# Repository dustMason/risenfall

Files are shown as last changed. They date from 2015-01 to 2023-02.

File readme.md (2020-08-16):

LED specs
===

All values calculated based on a 5v supply.

Table 1
---

Number | Color | Wattage | Current Draw | Fwd Voltage    | Resistor
------ | ----- | ------- | ------------ | -------------- | -------------
1      | White | ?       | 18mA         | 3-3.2v         | 120ohm / 1/8W
2      | White | ?       | 18mA         | 3-3.2v         | 120ohm / 1/8W
3      | White | 1W      | 330mA        | 3.2v           | 5.6ohm / 1W
4      |       |         |              |                | (missing LED)
5      | White | 1W      | 330mA        | 3.2v           | 5.6ohm / 1W
6      | White | 1W      | 330mA        | 3.2v           | 5.6ohm / 1W
7      | White | ?       | 18mA         | 3.2v           | 120ohm / 1/8W
8      | White | 1W      | 330mA        | 3.2v           | 5.6ohm / 1W

Table 2
---

Number | Color | Wattage | Current Draw | Fwd Voltage    | Resistor
------ | ----- | ------- | ------------ | -------------- | -------------
9      | Green | ?       | 16mA         | 2.9-3.1v       | 120ohm / 1/4W
10     | Green | ?       | 16mA         | 2.9-3.1v       | 220ohm / 1/4W
11     | White | ?       | 20mA         | 3-3.2v         | 100ohm / 1/8W
12     | Blue  | ?       | 18mA         | 3-3.2v         | 120ohm / 1/8W
13     | White | ?       | ?            | ?              | ? (light is dead)
14     | Blue  | ?       | 18mA         | 3-3.2v         | 120ohm / 1/8W
15     | White | ?       | 20mA         | 3-3.2v         | 100ohm / 1/8W
16     | Blue  | ?       | 18mA         | 3-3.2v         | 120ohm / 1/8W 
17     | White | ?       | 20mA         | 3-3.2v         | 100ohm / 1/8W 
18     | Blue  | ?       | 18mA         | 3-3.2v         | 120ohm / 1/8W 
19     | White | 1W      | 330mA        | 3.2v           | 5.6ohm / 1W

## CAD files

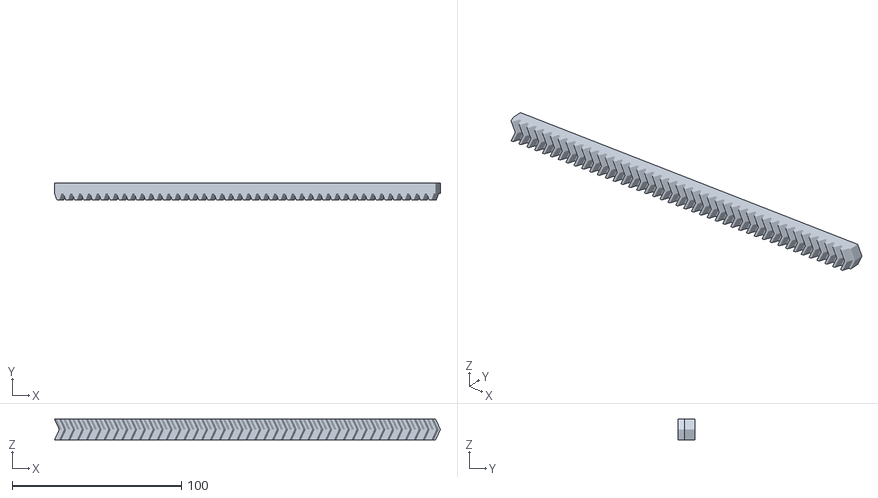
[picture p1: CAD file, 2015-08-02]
models/herringbone-rack.stl
228.0 x 9.85 x 12.2

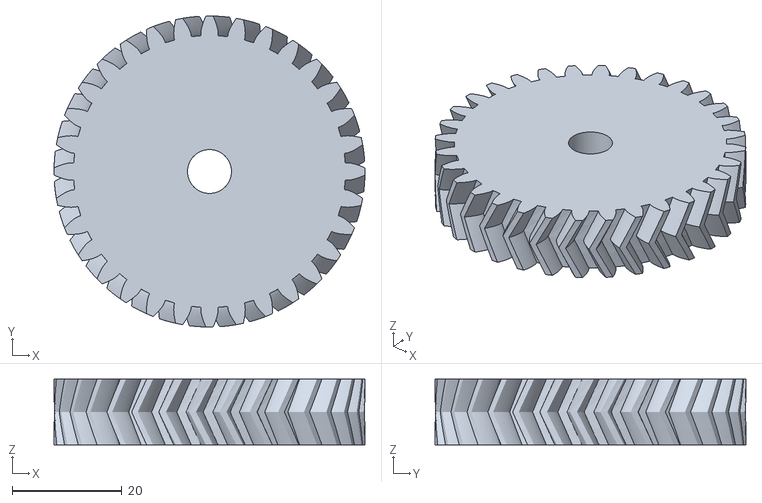
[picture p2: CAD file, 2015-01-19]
models/herringbone-gear.stl
56.7 x 56.7 x 12.0

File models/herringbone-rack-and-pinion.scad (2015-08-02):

// Parametric Modular Rack Andrew Ziobro
//Based on the work of MattMoses and Fdavies and Mark "Ckaos" Moissette:
//http://forums.reprap.org/read.php?1,51452,52099#msg-52099
//and Forrest Higgs:
// http://technocraticanarchist.blogspot.com/2010/01/high-speed-alternative-to-belts.html
//and http://www.thingiverse.com/thing:6011 info at :www.kaosat.net 
//and http://www.thingiverse.com/thing:3575 Parametic_involute_gear_v5.0
//It is licensed under the Creative Commons - GNU GPL license.
// © 2011 by Andrew Ziobro


//Download parametric_involute_gear_v5.0.scad from http://www.thingiverse.com/thing:3575
use <parametric_involute_gear_v5.0.scad>;

$fn=50;
pi=3.1415926535897932384626433832795;

innerRadius=5.1;
borders=1;
diametralPitch=12; // was 12
numberOfTeeth=43;
pressureAngle=20*pi/180;
centerAngle=25; // angle at center of teeth

rack(innerRadius,borders,diametralPitch,numberOfTeeth,pressureAngle,centerAngle);
// translate([0,-35.4,0]) {
// makeTetrixGear();
// }

module makeTetrixGear() {
	wheelSize=12;
	rotate([0,0,180]) {
		translate(0) {
			gear (
				number_of_teeth=32,
				circular_pitch=300,
				diametral_pitch=diametralPitch,
				pressure_angle=19.34,
				gear_thickness=wheelSize/2,
				rim_thickness=wheelSize/2,
				hub_thickness=0,
				bore_diameter=8,
				backlash=0,twist=centerAngle/4,involute_facets=15
			);
		}
		translate([0,0,wheelSize/2]) {
			rotate([0,0,-centerAngle/4]) {
				gear (
					number_of_teeth=32,
					circular_pitch=300,
					diametral_pitch=diametralPitch,
					pressure_angle=19.34,
					gear_thickness=wheelSize/2,
					rim_thickness=wheelSize/2,
					hub_thickness=0,
					bore_diameter=8,
					backlash=0,twist=-centerAngle/4,involute_facets=15
				);
			}
		}
	}
}


			
//rotate (a=[0,0,0]) translate([0,0,-1]) difference(){

module rack(innerRadius,borders,P,N,PA,CA) {
	// P = diametral pitch
	// N = number of teeth
	// PA = pressure angle in radians
	// x, y = linear offset distances
	a = 1/P; // addendum (also known as "module")
	d = 1.25/P; // dedendum (this is set by a standard)
	multiplier=20;//20
	height=(d+a)*multiplier;
	// echo(height);
	
	// find the tangent of pressure angle once
	tanPA = tan(PA*(180/pi));
	// length of bottom and top horizontal segments of tooth profile
	botL = (pi/P/2 - 2*d*tanPA)*multiplier;
	topL =( pi/P/2 - 2*a*tanPA)*multiplier;

	slantLng=tanPA*height;
	realBase=2*slantLng+topL;
	
	offset=topL+botL+2*slantLng;
	length=(realBase+botL)*N;
	echo("Offset:",offset);
	supportSize=(innerRadius+borders)*2;

	//calculate tooth params
	basesegmentL=realBase/2;
	basesegmentW=supportSize/2;

	topsegmentL=topL/2;
	topsegmentW=supportSize/2;

	baseoffsetY=tan(CA)*basesegmentW;
	topoffsetY=tan(CA)*topsegmentW;
	
	//calculate support params

	totalSupportLength=(N)*(offset);
	supportL=totalSupportLength/2;
	supportW=supportSize/1.9;
	
	echo("Total length",totalSupportLength+baseoffsetY);
	echo("Total height",supportSize);

	
	rotate([90,90,0]) {
		translate([-supportSize/2,supportSize/2,0]) {
			union() {
				difference()	{
					translate([0,0,supportSize/4]) {
						support(supportL,supportW-0.33,supportSize/2,baseoffsetY);	 
					}
				}
				for (i = [0:N-1]) {
					translate([0,i*offset-length/2+realBase/2,supportSize/2+height/2]) {			
						tooth(basesegmentL,basesegmentW,topsegmentL,topsegmentW,height,baseoffsetY,topoffsetY);		
					}
				}
			}
		}
	}
}

module support(supportL,supportW,height,offsetY) {
	tooth(supportL,supportW,supportL,supportW,height,offsetY,offsetY);
}



module tooth(basesegmentL,basesegmentW,topsegmentL,topsegmentW,height,baseoffsetY,topoffsetY)//top : width*length, same for base
{
	
	////////////////
	basePT1=[
	-basesegmentW,
	basesegmentL-baseoffsetY,
	-height/2];

	basePT2=[
	0,
	basesegmentL,
	-height/2];

	basePT3=[
	basesegmentW,
	basesegmentL-baseoffsetY,
	-height/2];

	basePT4=[
	basesegmentW,
	basesegmentL-(baseoffsetY+basesegmentL*2),
	-height/2];
	
	basePT5=[
	0,
	-basesegmentL,
	-height/2];

	basePT6=[
	-basesegmentW,
	basesegmentL-(baseoffsetY+basesegmentL*2),
	-height/2];
	//////////////////////////
	topPT1=[
	-topsegmentW,
	topsegmentL-topoffsetY,
	height/2];

	topPT2=[
	0,
	topsegmentL,
	height/2];

	topPT3=[
	topsegmentW,
	topsegmentL-topoffsetY,
	height/2];

	topPT4=[
	topsegmentW,
	topsegmentL-(topoffsetY+topsegmentL*2),
	height/2];
	
	topPT5=[
	0,
	-topsegmentL,
	height/2];

	topPT6=[
	-topsegmentW,
	topsegmentL-(topoffsetY+topsegmentL*2),
	height/2];
	//////////////////////////

	//////////////////////////

	polyhedron(
	points=[
		basePT1,
		basePT2,
		basePT3,
		basePT4,
		basePT5,
		basePT6,
		topPT1,
		topPT2,
		topPT3,
		topPT4,
		topPT5,
		topPT6],
	triangles=[
	//base
	[5,1,0],
	[4,1,5],
	[4,2,1],
	[3,2,4],	

	//front
	[1,6,0],
	[7,6,1],
	[2,7,1],
	[8,7,2],
	//back
	[11,10,5],
	[5,10,4],
	[10,9,4],
	[4,9,3],	
	//side 1
	[0,11,5],
	[6,11,0],
	//side 2
	[3,8,2],
	[9,8,3],
	//top
	[9,10,8],
	[10,7,8],
	[11,7,10],
	[6,7,11],
	]
	);
}

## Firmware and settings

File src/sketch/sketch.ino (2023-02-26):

#include <math.h>
#include <Wire.h>
#include <Adafruit_PWMServoDriver.h>

#define CONTINOUS_SERVOMIN 172 // see `table 3 servo formula` comment below
#define CONTINOUS_SERVOMAX 565 // see `table 3 servo formula` comment below
#define MICRO_SERVOMIN 500     // this is the 'minimum' pulse length count (out of 4096)
#define MICRO_SERVOMAX 2400    // this is the 'maximum' pulse length count (out of 4096)
#define CURVE -4.5             // log curve weight (between -10 and 10)

// --- table 3 servo formula --
// - 60Hz is the update cycle for table 3 servo (PWM driver sends 60 pulses per second)
// - each pulse has 4096 ticks (4096 ticks = 1/60th of a second)
// - 1/60th of a second = 16,666.667 useconds
// - min/stop/max of FS90R is 700/1500/2300 useconds per the datasheet
// min -> 700 / 16666 * 4096 = 172.03
// stop -> 1500 / 16666 * 4096 = 368.65 (theoretical. in practice the stop value is 400)
// max -> 2300 / 16666 * 4096 = 565.27
// (from testing, the servo stops at midi cc value 77. 77 equates to 400 PWM value)


#define TABLE_3_SERVO_LIMIT_LEFT 22        // pin numbner
#define TABLE_3_SERVO_LIMIT_RIGHT 23       // pin number
#define TABLE_3_SERVO_OFF_PULSELENGTH 4096 // at one point was 410, but turning off the pin is better
#define TABLE_3_SERVO_MIDI_STOP 77

Adafruit_PWMServoDriver board1 = Adafruit_PWMServoDriver(0x40);
Adafruit_PWMServoDriver board2 = Adafruit_PWMServoDriver(0x41);
Adafruit_PWMServoDriver board3 = Adafruit_PWMServoDriver(0x42);
Adafruit_PWMServoDriver servos = Adafruit_PWMServoDriver(0x43);
Adafruit_PWMServoDriver board4 = Adafruit_PWMServoDriver(0x44);
Adafruit_PWMServoDriver board5 = Adafruit_PWMServoDriver(0x45); 
Adafruit_PWMServoDriver board6 = Adafruit_PWMServoDriver(0x46);

boolean table_3_servo_limit_left = false;
boolean table_3_servo_limit_right = false;
boolean table_3_servo_turning_left = false;
boolean table_3_servo_turning_right = false;

void OnControlChange(byte channel, byte controlNumber, byte amount) {
  uint8_t pwmChannel = ((uint8_t) controlNumber) - 1;
  if (channel == 16) {
    uint16_t pulselen;
    if (pwmChannel < 8) {
      pulselen = map(amount, 0, 127, MICRO_SERVOMIN, MICRO_SERVOMAX);
    } else if (pwmChannel == 15) {
      if (
        (table_3_servo_limit_right && amount < TABLE_3_SERVO_MIDI_STOP) || // trying to turn right
        (table_3_servo_limit_left && amount > TABLE_3_SERVO_MIDI_STOP)     // trying to turn left
      ) {
        pulselen = uint16_t(TABLE_3_SERVO_OFF_PULSELENGTH);
      } else {
        if (amount < TABLE_3_SERVO_MIDI_STOP) {
          table_3_servo_turning_left = false;
          table_3_servo_turning_right = true;
        } else if (amount > TABLE_3_SERVO_MIDI_STOP) {
          table_3_servo_turning_left = true;
          table_3_servo_turning_right = false;
        } else {
          table_3_servo_turning_left = false;
          table_3_servo_turning_right = false;
        }
        pulselen = map(amount, 0, 127, CONTINOUS_SERVOMIN, CONTINOUS_SERVOMAX);
      }
    } else {
      pulselen = map(amount, 0, 127, CONTINOUS_SERVOMIN, CONTINOUS_SERVOMAX);
    }
    servos.setPWM(pwmChannel, 0, pulselen);
  } else {
    uint16_t brightness;
    if (amount == 0) {
      brightness = 4096;
    } else {
      brightness = fscale(0, 127, 0, 4095, amount, CURVE);
    }
    if (channel == 1) {
      board1.setPWM(pwmChannel, 0, brightness);
    } else if (channel == 2) {
      board2.setPWM(pwmChannel, 0, brightness);
    } else if (channel == 3) {
      board3.setPWM(pwmChannel, 0, brightness);
    } else if (channel == 4) {
      board4.setPWM(pwmChannel, 0, brightness);
    } else if (channel == 5) {
      board5.setPWM(pwmChannel, 0, brightness);
    } else if (channel == 6) {
      board6.setPWM(pwmChannel, 0, brightness);
    }
  }
}

void checkTable3ServoLimits() {
  table_3_servo_limit_left = (digitalRead(TABLE_3_SERVO_LIMIT_LEFT) == LOW);
  table_3_servo_limit_right = (digitalRead(TABLE_3_SERVO_LIMIT_RIGHT) == LOW);
  if (table_3_servo_limit_right && table_3_servo_turning_right) {
    servos.setPWM(15, 0, uint16_t(TABLE_3_SERVO_OFF_PULSELENGTH));
    table_3_servo_turning_right = false;
  } else if (table_3_servo_limit_left && table_3_servo_turning_left) {
    servos.setPWM(15, 0, uint16_t(TABLE_3_SERVO_OFF_PULSELENGTH));
    table_3_servo_turning_left = false;
  }
}

void setup() { 
  board1.begin();
  board1.setPWMFreq(1600);
  board2.begin();
  board2.setPWMFreq(1600);
  board3.begin();
  board3.setPWMFreq(1600);
  board4.begin();
  board4.setPWMFreq(1600);
  board5.begin();
  board5.setPWMFreq(1600);
  board6.begin();
  board6.setPWMFreq(1600);
  servos.begin();
  servos.setPWMFreq(60); // Analog servos run at ~60 Hz updates
  usbMIDI.setHandleNoteOn(OnNoteOn);
  usbMIDI.setHandleControlChange(OnControlChange);
  pinMode(TABLE_3_SERVO_LIMIT_LEFT, INPUT_PULLUP);
  pinMode(TABLE_3_SERVO_LIMIT_RIGHT, INPUT_PULLUP);
  servos.setPWM(15, 0, uint16_t(TABLE_3_SERVO_OFF_PULSELENGTH)); // start the servo OFF
} // add code here for boards

void loop() {
  checkTable3ServoLimits();
  usbMIDI.read();
}

void OnNoteOn(byte channel, byte note, byte velocity) {
  // zilch. strangely, controlChange doesn't work without a noteOn handler
}

// from http://playground.arduino.cc/Main/Fscale
float fscale(float originalMin, float originalMax, float newBegin, float newEnd, float inputValue, float curve) {
  float originalRange = 0;
  float newRange = 0;
  float zeroRefCurVal = 0;
  float normalizedCurVal = 0;
  float rangedValue = 0;
  boolean invFlag = 0;
  if (curve > 10) curve = 10;
  if (curve < -10) curve = -10;
  curve = (curve * -.1); // postive numbers give more weight to high end on output
  curve = pow(10, curve); // convert linear scale into lograthimic exponent for other pow function
  if (inputValue < originalMin) { inputValue = originalMin; }
  if (inputValue > originalMax) { inputValue = originalMax; }
  originalRange = originalMax - originalMin;
  if (newEnd > newBegin) {
    newRange = newEnd - newBegin;
  } else {
    newRange = newBegin - newEnd;
    invFlag = 1;
  }
  zeroRefCurVal = inputValue - originalMin;
  normalizedCurVal  =  zeroRefCurVal / originalRange; // normalize to 0 - 1 float
  if (originalMin > originalMax ) { return 0; }
  if (invFlag == 0){
    rangedValue = (pow(normalizedCurVal, curve) * newRange) + newBegin;
  } else {
    rangedValue = newBegin - (pow(normalizedCurVal, curve) * newRange);
  }
  return rangedValue;
}

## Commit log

2014-12-08 Recording the goddamned LED specs once and for all
2014-12-21 Add servo board driver
2015-01-05 Increase max servo speed
2015-01-10 Experimental logarithmic curve feature for brightness
    also example addition of another PWMServoDriver
2015-01-10 init new pwm driver
2015-01-12 Dont need servo board for now, add board 3
2015-01-19 3d models of rack and pinion
    [herringbone-gear.stl, herringbone-rack-and-pinion.scad, herringbone-rack.stl]
2015-01-19 servo driver at 0x43
2015-01-19 micro servos vs continous
2015-01-19 fix control channel issue
    [sketch.ino]
2015-01-19 Use Austin's corrected micro servo pulse width values
    [sketch.ino]
2015-08-02 model updates
    [herringbone-rack-and-pinion.scad, herringbone-rack.stl]
2015-08-02 servo limit switches
